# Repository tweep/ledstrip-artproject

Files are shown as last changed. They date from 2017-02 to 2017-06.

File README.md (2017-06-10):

# Ledstrip Art project 
This project aims to make an LED art installation of the Vasily Kadinsky "einige kreise" picture - see pictures below. 
The installation will be driven by 2 Arduino Mega 2560's ( one for the LEDs, one for a remote control ); each colored 
circle can change color independently.  

Here's the final installation - you fine some pictures if you scroll down, or look [here](./pics/)

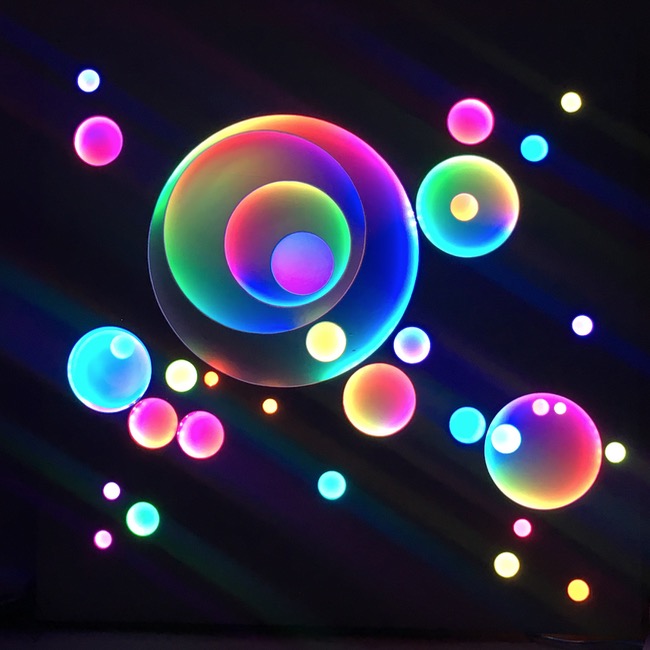
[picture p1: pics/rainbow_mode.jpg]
Final installation
 

## What i could have done better
- every plywood sheet should have had a SINGLE connector to connect to the MAIN sheet with 
  the microcontrollers. Currently I have one centralized place where all connects - so taking the 
  whole piece apart is a big mess as i have to disconnect 36 connectors and loose all the pin-layout. 
  Not good. Next time, one central connector per Plywood sheet, with a single cable running to 
  the microcontroller. Not 1000's of cables. it's also easer to build as you can measure the
  length of the cables better. 
- do the edges in an angled fashion so it looks more like "floating" / cut the sides in angles
  where the top plywood is smaller than the one below, than the one below, than the one below...

## Notes 
Here are some good reads on colors and color theory: 

[The color wheel](https://blog.asmartbear.com/color-wheels.html) 
[Hue angle transitions](http://rileyjshaw.com/blog/hue-angle-transitions/)

I created a nice color transition in [JSfiddle](https://jsfiddle.net/user/vogelj/).

## Stuff needed 
- thin pywood sheets ( 5mm think so it's not too heavy 
  ( home depot, cut the 8x4 sheets into 4 x 4 squares ) 
- 2 x Arduino Mega 2560 
- LED strips WS2812B 5V
- Power supply : I ordered a fan-less Mean Well HSN 300 watts 5V supply. 
  (That's 60 Amps - I went a little over the top as i did not now at the start 
   how many LEDs I have to power. I used 700 LEDS which need  42 Amps max. 
  [Power supply](http://www.trcelectronics.com/View/Mean-Well/HSN-300-5A.shtml)
- JST connectors and 3-cables from Amazon
- Soldering iron 
- Solder - Mandala Crafts 60 40 0.6mm 0.8mm 1mm 1.5mm 2% Flux Rosin Core Solder Wire (50g, 60 40, 0.8mm)
  https://www.amazon.com/dp/B06XX27KZ1/

## Libraries /  Software / Dependencies
I'm using the FastLED library to drive my WS2812B 5V LED strips which have individually addressable LEDs. I bought them online. 
 
- [Arduino FastLED library](https://github.com/FastLED/FastLED)
- Infrared library ( currently used: : IRemote. I like to switch to the IRlib2 later. It has conflicts with the interrupts used by FastLED, 
  so I decided to use 2 Arduinos: one to deal with the remote and the LCD display, and one which drives the LEDs.
- [Easytransfer_I2C](has://github.com/madsci1016/Arduino-EasyTransfer) - to communicate between 2 Arduinos via Serial interface 

## Project status and files 
After realizing that there are some timing problems when using the FastLed library together with an IR-remote (the FastLed library turns all interrrupts off), I decided to use 2 Arduino boards for the project: 

 1.  1 x Arduino MEGA to drive the User interface ( the MASTER) 
 * LCD display with keypad 
 * Menu structure on LCD 
 * IR receiver to remote control the same menu with an IR remote 
 * uses EasyTransfer library to send data via I2C to the Arduino Mega  

 2.  1 x Arduino MEGA which controls the FastLED patterns and strands (the SLAVE)
 * uses FastLED library to drive the strands 
 * EasyTransfer library to receive data via I2C from the Arduino Uno menu / UI and translate them into 
   visible patterns
 * code for patterns, transitions, and FastLED configuration 
 * I'm driving 700 LEDS distributed over 36 strands. Each strand has a differnt number of LEDs; 
   this was a bit of a challenge as the 'usual' way of using a two-dimensional array for all LEDS 
   eats up too much memory. 
   I had to modfify the FastLED library to add some methods which allow me to work with a different 
   data structure.

## Todo 
- switch to differnt IR library ( see [example](./EXAMPLE_irlib2_remote_fastled)
- 
## Code  

## Code Stages 

### UNO_LCD_I2C_TX_example 
File UNO_LCD_I2C_TX_example.ino contains a fully working example for the Arduino Uno which 
  - shows a menu for 2 LED strands + some global configuration 
  - interfaces with an IR remote to use the menu   
  - interfaces with a keypad on the menu to choose functions 
  - sends the data to the Arduno Mega via I2C communication 

This example uses the following libraries: 
 - Wire.h
 - EasyTransferI2C.h
 - LiquidCrystal.h
 - MenuEntry.h"
 - MenuLCD.h"
 - MenuManager.h"
 - IRremote.h
 - IRremoteInt.h

## Todo: 

- allow to control brightness of strands individuall ( could be combined with the on/off possibility )    
- allow to switch individual strands on/off 

- Create solid patterns: red, green, blue
  Create solid transitions of full strand : red -> green -> blue -> ...
- add new transitons ( turning / rgb color circles ) 
- add beserker mode ( blinking in high frequency with different colors ) 

- store favorite configs and add possibility to cycle trough them. [ 0, 2, 1, 0 ] ... strips don't need to be all the same theme

- adjust speed of some patterns ? 

## Done : 
- reset function [ go back to start config ] 
- add possibility to cycle all strands trough all patterns together 
- switch all strands on / off 
- control brightness of all strands with single button  
- change the strand themes individually per strand 

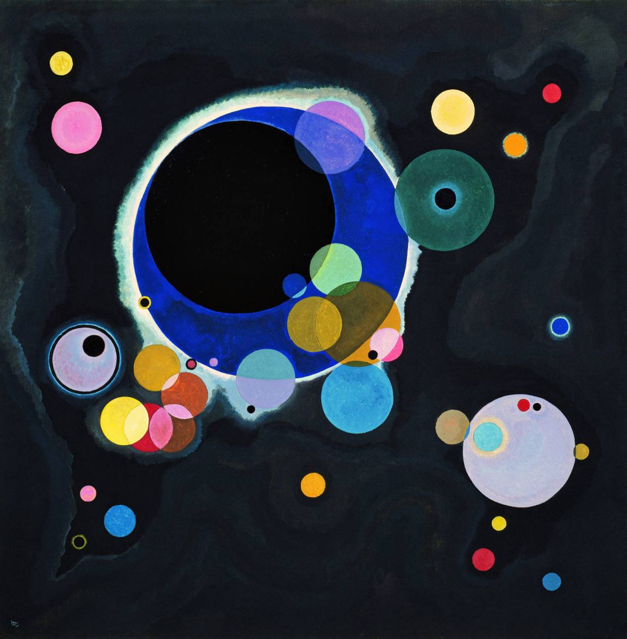
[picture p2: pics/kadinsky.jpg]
Kadinsky picture
 

Final installation 

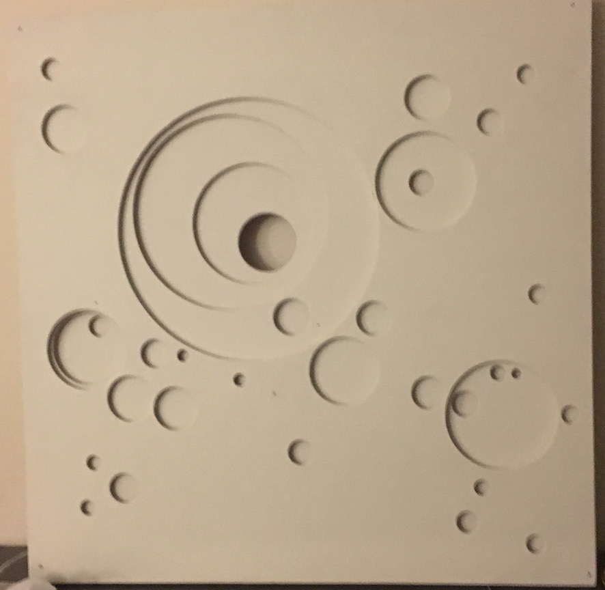
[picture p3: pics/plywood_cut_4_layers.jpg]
Daylight
 

More pictures can be found [here](./pics/.jpg)

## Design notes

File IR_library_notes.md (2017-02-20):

# Notes on IR Libraries 

There are serveral libraries out there which support IR receviers ( and the sending of IR signals). The first library was written by Ken Shirriff. 

## IRremote.h and IRremoteInt.h 
Written by Ken Shiriff. Latest version: 2.2.1 
Available here: https://github.com/shirriff/Arduino-IRremote
Works ok, but seems to not handle interrupts - the IR singal gets only read 
every now-and-than.  
Conflicts: No conflicts with FastLED libary.

## IRlib 
Writteb by Cyborg5. 
Available here : https://github.com/cyborg5/IRLib/
Conflicts: 

## IRlib2  
Written by Cyborg.
Available here: https://github.com/cyborg5/IRLib2
Conflicts: This library has problems when used with the FastLED library - when calling the delay function ( which sets the frame rate ) - the IR remote codes are not read correctly anymore: 

     FastLED.delay(40) 

## Infrared4Arduino
Written by bengtmartensson
Available here : https://github.com/bengtmartensson/Infrared4Arduino/
http://www.harctoolbox.org/Infrared4Arduino.html
Conflicts: ? 
Notes: Unsure if this lib works with interrupts or not.

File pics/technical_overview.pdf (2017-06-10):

# Kandinsky goes LED!

Jan Vogel

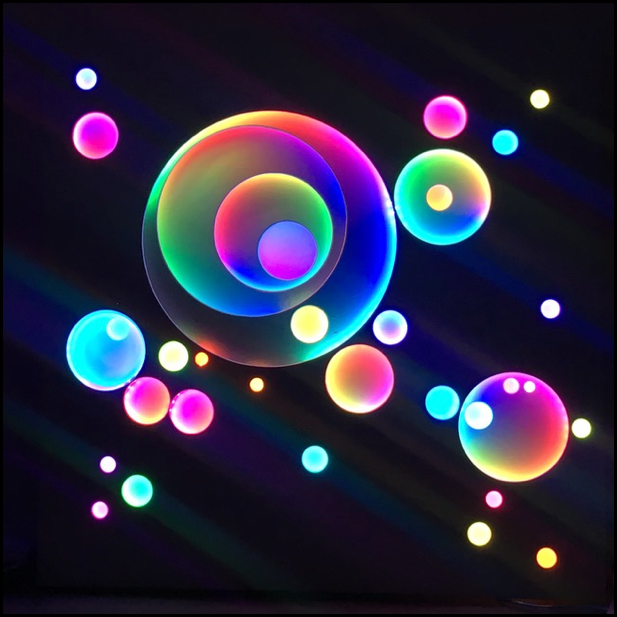
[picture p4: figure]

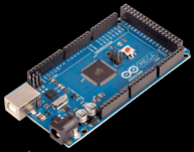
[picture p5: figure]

I2C communication

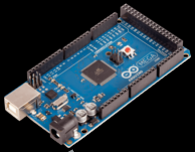
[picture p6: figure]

36 WS2812B
LED strips
(700 LEDs)

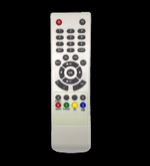
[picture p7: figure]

700 * 60 mA / 1000 = 42 Amp

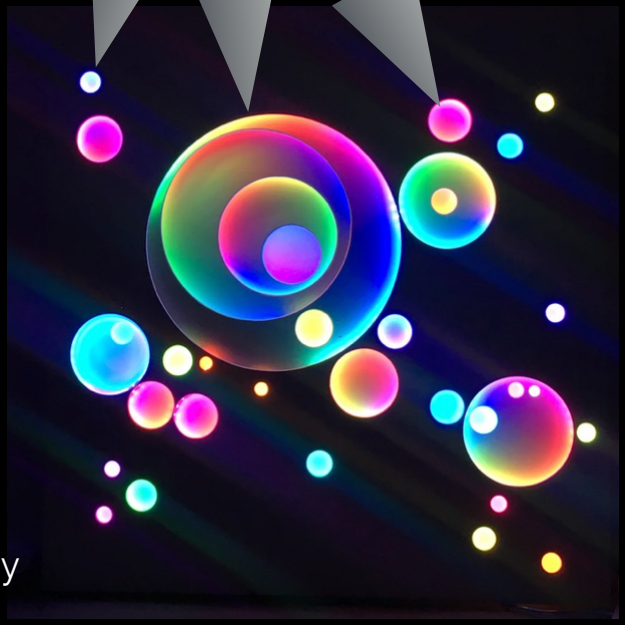
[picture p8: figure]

300 w / 5 V / 60 Amp fan-less power supply Mean Well HSN-300-5A

SEND_DATA_STRUCTURE{
int ledStripToConfigure;
int pattern;
int spd;
int bright;
int color;
} sendLEDConfig;

# To do better

- for global config changes ( like turn stuff off ), only send 1 config, and the SLAVE should then loop trough all strands and set the defaults (so we don’t have to send 36 configswe just send a single GLOBAL config which SLAVE resolves into 36 smaller ones
- more patterns
- easy way to make new patterns
- new IR library to resolve the fuzzy control via IR
- fix the one weird LED strand

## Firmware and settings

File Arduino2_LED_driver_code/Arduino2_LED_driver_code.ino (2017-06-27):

/* ARDUINO LED SLAVE 
   - drives the LEDS strands
   - knows all about the strands ( nr LEDs and PINs)
   - implementes their actions (transitions)
*/   

#include <Wire.h>
#include <EasyTransferI2C.h>
#include <FastLED.h>

FASTLED_USING_NAMESPACE
#define COLOR_ORDER GRB
#define ARRAY_SIZE(A) (sizeof(A) / sizeof((A)[0]))
#define I2C_SLAVE_ADDRESS 9

#define NUM_STRIPS 36

 
CRGB leds[774]; // one-dimensional array, better memory use.

/* methods to try ;
 *  fill_solid( leds, int numToFill,  const struct CRGB& color)  // operates on an array of LEDS rather; needs to operate on an array + an offset instead 
 *  fill_rainbow( leds, numtofill ) - fills a whole strip with rainbow colors
 *  Sigh, all methods opereate on an array of LEDs
 *  
 */

/* Another way to do this is : 36 of these arrays. Maybe can we have one array with pointers to point to these ? 
 *  How can we create an array of pointers ? in a for loop ? 
 *  for ( num strips ) { 
 *    ledRegister[1] = *create_array_with_leds(size) 
 *    }
 * CRGB redLeds[10];
   CRGB greenLeds[60];
   CRGB blueLeds[];
 */


/*       STRAND    S0  S1  S2  S3  S4   5   6   7   8  9   10   11  12 13  14   15  16  17  18  19  20  21   22  23  24  25  26  27  28  29  30  31 32   33 34  35
 *       NR_LEDS   13, 21, 46, 31, 12, 10, 11, 14, 19, 17, 12,  5, 90, 75,  60, 28, 15, 7,  12, 27, 14, 36,  15, 19, 14, 12, 12, 14, 41, 14, 8,  6, 8,    9, 12, 15 
 *          PIN    47  32  49   5  34  31   2   3   8  7   24   23  6  12   4   35  51  22  36  25  11  45   43  44  27  53  50  48  10  13  52  46 9    26 28, 29

*/

                   //        STRAND    S0  S1  S2  S3  S4 -  5   6   7   8   9  -  10  11  12  13  14 -  15  16  17  18  19 - 20  21  22  23  24  - 25  26  27  28  29 - 30  31  32  33  34  35
byte nrLedsPerStrand[NUM_STRIPS]    = {13, 21, 46, 31, 12,  10, 11, 14, 19, 17,    12,  5, 90, 75, 60,   28, 15,  7, 12, 27,  14, 36, 15, 19, 14,   12, 12, 14, 41, 14,   8,  6,  8,  9, 12, 15 };
//byte stripPin[NUM_STRIPS]           = {47, 32, 49,  5, 34,  31,  2,  3,  8,  7,    24, 23,  6, 12,  4,   35, 51,  22,36, 25,  11, 45, 43, 44, 27,   53, 50, 48, 10, 13,  52, 46,  9, 26, 28, 29 };



EasyTransferI2C ET;


// ---- global variables to store data for the PATTERNS
boolean gSwitch               = true; // global variable to remember current ON/OFF status
byte    gstrand               = 0;    // global variable to point to current strand.
byte    gHue[NUM_STRIPS]      = {0, 0, 0, 0, 0, 0, 0, 0, 0, 0, 0, 0, 0, 0, 0, 0, 0, 0, 0, 0, 0, 0, 0, 0, 0, 0, 0, 0, 0, 0, 0, 0, 0, 0, 0,0 };  // rotating "base color" used by many of the patterns, so each strip can have different gHue

// TODO Master: have longer sleep timer in setup()
// sleep timer - to turn LED off after 60 min.

struct RECEIVE_DATA_STRUCTURE {
  //THIS MUST BE EXACTLY THE SAME ON THE OTHER ARDUINO
  int ledStripToConfigure;
  int pattern;
  int spd;
  int bright;
  int color;
} mydata;

typedef struct {    // Structure to hold a copy of the configuration of each strand
  int pattern;
  int spd;
  int bright;
  int color;
} struct_ledconf;
struct_ledconf ledConfig[NUM_STRIPS];

CLEDController *controllers[NUM_STRIPS];


void setup() {
  Serial.begin(115200);

  controllers[0] = &FastLED.addLeds<WS2812B, 47>(leds, getOffsetOfStrand(0), nrLedsPerStrand[0]).setCorrection(TypicalLEDStrip);
  controllers[1] = &FastLED.addLeds<WS2812B, 32>(leds, getOffsetOfStrand(1), nrLedsPerStrand[1]).setCorrection(TypicalLEDStrip);
  controllers[2] = &FastLED.addLeds<WS2812B, 49>(leds, getOffsetOfStrand(2), nrLedsPerStrand[2]).setCorrection(TypicalLEDStrip);
  controllers[3] = &FastLED.addLeds<WS2812B,  5>(leds, getOffsetOfStrand(3), nrLedsPerStrand[3]).setCorrection(TypicalLEDStrip);
  controllers[4] = &FastLED.addLeds<WS2812B, 34>(leds, getOffsetOfStrand(4), nrLedsPerStrand[4]).setCorrection(TypicalLEDStrip);

  controllers[5] = &FastLED.addLeds<WS2812B, 31, GRB>(leds,getOffsetOfStrand(5),nrLedsPerStrand[5]).setCorrection(TypicalLEDStrip);
  controllers[6] = &FastLED.addLeds<WS2812B,  2, GRB>(leds,getOffsetOfStrand(6),nrLedsPerStrand[6]).setCorrection(TypicalLEDStrip);
  controllers[7] = &FastLED.addLeds<WS2812B,  3, GRB>(leds,getOffsetOfStrand(7),nrLedsPerStrand[7]).setCorrection(TypicalLEDStrip);
  controllers[8] = &FastLED.addLeds<WS2812B,  8, GRB>(leds,getOffsetOfStrand(8),nrLedsPerStrand[8]).setCorrection(TypicalLEDStrip);
  controllers[9] = &FastLED.addLeds<WS2812B,  7, GRB>(leds,getOffsetOfStrand(9),nrLedsPerStrand[9]).setCorrection(TypicalLEDStrip);

  controllers[10] = &FastLED.addLeds<WS2812B, 24, GRB>(leds,getOffsetOfStrand(10),nrLedsPerStrand[10]).setCorrection(TypicalLEDStrip);
  controllers[11] = &FastLED.addLeds<WS2812B, 23, GRB>(leds,getOffsetOfStrand(11),nrLedsPerStrand[11]).setCorrection(TypicalLEDStrip);
  controllers[12] = &FastLED.addLeds<WS2812B,  6, GRB>(leds,getOffsetOfStrand(12),nrLedsPerStrand[12]).setCorrection(TypicalLEDStrip);
  controllers[13] = &FastLED.addLeds<WS2812B, 12, GRB>(leds,getOffsetOfStrand(13),nrLedsPerStrand[13]).setCorrection(TypicalLEDStrip);
  controllers[14] = &FastLED.addLeds<WS2812B,  4, GRB>(leds,getOffsetOfStrand(14),nrLedsPerStrand[14]).setCorrection(TypicalLEDStrip);

  controllers[15] = &FastLED.addLeds<WS2812B, 35, GRB>(leds,getOffsetOfStrand(15),nrLedsPerStrand[15]).setCorrection(TypicalLEDStrip);
  controllers[16] = &FastLED.addLeds<WS2812B, 51, GRB>(leds,getOffsetOfStrand(16),nrLedsPerStrand[16]).setCorrection(TypicalLEDStrip);
  controllers[17] = &FastLED.addLeds<WS2812B, 22, GRB>(leds,getOffsetOfStrand(17),nrLedsPerStrand[17]).setCorrection(TypicalLEDStrip);
  controllers[18] = &FastLED.addLeds<WS2812B, 36, GRB>(leds,getOffsetOfStrand(18),nrLedsPerStrand[18]).setCorrection(TypicalLEDStrip);
  controllers[19] = &FastLED.addLeds<WS2812B, 25, GRB>(leds,getOffsetOfStrand(19),nrLedsPerStrand[19]).setCorrection(TypicalLEDStrip);


  controllers[20] = &FastLED.addLeds<WS2812B, 11, GRB>(leds,getOffsetOfStrand(20),nrLedsPerStrand[20]).setCorrection(TypicalLEDStrip);
  controllers[21] = &FastLED.addLeds<WS2812B, 45, GRB>(leds,getOffsetOfStrand(21),nrLedsPerStrand[21]).setCorrection(TypicalLEDStrip);
  controllers[22] = &FastLED.addLeds<WS2812B, 43, GRB>(leds,getOffsetOfStrand(22),nrLedsPerStrand[22]).setCorrection(TypicalLEDStrip);
  controllers[23] = &FastLED.addLeds<WS2812B, 44, GRB>(leds,getOffsetOfStrand(23),nrLedsPerStrand[23]).setCorrection(TypicalLEDStrip);
  controllers[24] = &FastLED.addLeds<WS2812B, 27, GRB>(leds,getOffsetOfStrand(24),nrLedsPerStrand[24]).setCorrection(TypicalLEDStrip);

  
  controllers[25] = &FastLED.addLeds<WS2812B, 53, GRB>(leds,getOffsetOfStrand(25),nrLedsPerStrand[25]).setCorrection(TypicalLEDStrip);
  controllers[26] = &FastLED.addLeds<WS2812B, 50, GRB>(leds,getOffsetOfStrand(26),nrLedsPerStrand[26]).setCorrection(TypicalLEDStrip);
  controllers[27] = &FastLED.addLeds<WS2812B, 48, GRB>(leds,getOffsetOfStrand(27),nrLedsPerStrand[27]).setCorrection(TypicalLEDStrip);
  controllers[28] = &FastLED.addLeds<WS2812B, 10, GRB>(leds,getOffsetOfStrand(28),nrLedsPerStrand[28]).setCorrection(TypicalLEDStrip);
  controllers[29] = &FastLED.addLeds<WS2812B, 13, GRB>(leds,getOffsetOfStrand(29),nrLedsPerStrand[29]).setCorrection(TypicalLEDStrip);
  
  controllers[30] = &FastLED.addLeds<WS2812B, 52, GRB>(leds,getOffsetOfStrand(30),nrLedsPerStrand[30]).setCorrection(TypicalLEDStrip);
  controllers[31] = &FastLED.addLeds<WS2812B, 46, GRB>(leds,getOffsetOfStrand(31),nrLedsPerStrand[31]).setCorrection(TypicalLEDStrip);
  controllers[32] = &FastLED.addLeds<WS2812B,  9, GRB>(leds,getOffsetOfStrand(32),nrLedsPerStrand[32]).setCorrection(TypicalLEDStrip);
  controllers[33] = &FastLED.addLeds<WS2812B, 26, GRB>(leds,getOffsetOfStrand(33),nrLedsPerStrand[33]).setCorrection(TypicalLEDStrip);
  controllers[34] = &FastLED.addLeds<WS2812B, 28, GRB>(leds,getOffsetOfStrand(34),nrLedsPerStrand[34]).setCorrection(TypicalLEDStrip);

  controllers[35] = &FastLED.addLeds<WS2812B, 29, GRB>(leds,getOffsetOfStrand(35),nrLedsPerStrand[35]).setCorrection(TypicalLEDStrip);


  for ( int j = 0; j < NUM_STRIPS; j++ ) {
    Serial.print("Strip"); 
    Serial.println(j); 
    FastLED[j].showLeds(128); // set initial brightness of strip
    FastLED.show();
    gstrand=j;
    colorStripBlack();
    delay(50);

    // set very initial config 
      ledConfig[j].pattern      = 6; 
      ledConfig[j].spd          = 0;
      ledConfig[j].bright       = 0;
      ledConfig[j].color        = 0;

    
  }

  // -------- EasyTransfer --------

  Wire.begin(I2C_SLAVE_ADDRESS);
  //start the library, pass in the data details and the name of the serial port. Can be Serial, Serial1, Serial2, etc.
  ET.begin(details(mydata), &Wire);
  Wire.onReceive(receive);   //define handler function on receiving data
  Serial.println("Ready to receive data");
}


typedef void (*SimplePatternList[])();
// array with list of patters which serve as functions. problem is we can't hand arguments over so we use global variables
SimplePatternList gPatterns = { //breathing_led_heartbeat, 
                               rainbow, 
                                rainbowWithGlitter, 
                                confetti, 
                                sinelon, 
                                juggle,
                                bpm, 
                                fadeToBlack,
                                colorStripRed };

int gNrPatterns = ARRAY_SIZE(gPatterns);


int getOffsetOfStrand (int strand) {
  int offset = 0;
  for (int i = 0; i < strand; i++) { 
    offset+= nrLedsPerStrand[i];   
  }
  return offset; 
}



void loop() {
  // BEGINNING OF -loop-
  
  if (ET.receiveData()) {
      int strip = mydata.ledStripToConfigure;

      // if we retrieve GLOBAL data we apply it to all strands 
      if (strip == -1) { 
           for (byte i = 0; i < NUM_STRIPS ; i++ ) {
             ledConfig[i].pattern      = ( mydata.pattern % gNrPatterns);
             ledConfig[i].spd          = mydata.spd;
             ledConfig[i].bright       = mydata.bright;
             ledConfig[i].color        = mydata.color;
             controllers[i]->showLeds(ledConfig[i].bright);
           }
      }else { 
        ledConfig[strip].pattern      = ( mydata.pattern % gNrPatterns);

        ledConfig[strip].spd          = mydata.spd;
        ledConfig[strip].bright       = mydata.bright;
        ledConfig[strip].color        = mydata.color;
        controllers[strip]->showLeds(ledConfig[strip].bright);
      
       Serial.println("Retrieving data...");
       Serial.print(" Strip: "); Serial.print(mydata.ledStripToConfigure);
       Serial.print(" pattern: "); Serial.print(mydata.pattern);
       Serial.print(" speed: "); Serial.print(mydata.spd);
       Serial.print(" brigh: "); Serial.print(mydata.bright);
       Serial.print(" color: "); Serial.print(mydata.color);
       Serial.println(" ");
      }
  }

  // Loop trough all strands and write/apply the values of the ledConfig to each strand.
  for (byte i = 0; i < NUM_STRIPS ; i++ ) {
    gstrand = i; // global index to point to current strand. gstrand (global Var!!) is used in the subroutines which do patterns. 
    // DONT change this !
    // the challenge is that we can't had this parameter over to the routine itself.
    gPatterns[ledConfig[i].pattern]();
    controllers[i]->showLeds(ledConfig[i].bright);
  }
 //  delay(3);
   // END OF -loop-
}

void receive(int numBytes) {
}

void breathing_led_heartbeat() {
  int offset = getOffsetOfStrand(gstrand);

  /* uploaded 26-06-2017
    todo:
      - only light up a certain nu ber of circles at the same time ( like 2,3,4 ) 
      - randomly switch to a new circle once the currenlty light cirlce is off
      - ( need a factor for each strand to define the speed of light on / light off 
      - not all cirlces adaapot the new (led breathing pattern - why ? ) some stay on the previous pattern.
      - refactor how global pattersn are sent. 
  */

  float val = (exp(sin(millis()/(gstrand*200.0)*PI)) - 0.36787944)*108.0;
  Serial.print("gstrand: ");
  Serial.print(gstrand);
  Serial.print("  val : ");
  Serial.print(val);
  Serial.print(" ghue :");
  Serial.println(gHue[gstrand]);

  // this can be done faster using the method in fill_rainbow() or fill_solid 
 // for (byte x=0; x< nrLedsPerStrand[gstrand]; x++){
  //   leds[offset+x] = CHSV( gHue[gstrand] , 128, 255); // random number from 0-255
// }
  ledConfig[gstrand].bright=val;

 fill_solid(&leds[offset], nrLedsPerStrand[gstrand],  CHSV( gHue[gstrand] , 255, 255));

 // only change the color once we 'breathed out'  
  if(val < 0.1 ){
    gHue[gstrand] = gHue[gstrand]+random8(0,25);
    //gHue[gstrand] = gHue[gstrand]+5;
     // gHue[gstrand] = random8();

  }
}




void rainbow() {
  // use global variable strand
  gHue[gstrand]++;

 //fill_rainbow( struct CRGB * pFirstLED, int numToFill, uint8_t initialhue, uint8_t deltahue = 5);

 //  fill_rainbow(leds , nrLedsPerStrand[gstrand], gHue[gstrand], 7);

  fill_rainbow(&leds[getOffsetOfStrand(gstrand)] , nrLedsPerStrand[gstrand], gHue[gstrand], 3);

 // fill_rainbow(leds, getOffsetOfStrand(gstrand) , nrLedsPerStrand[gstrand], gHue[gstrand], 7);

}

void rainbowWithGlitter() {
  rainbow();
  addGlitter(80);
}

// change individual pixel a strand
void addGlitter( fract8 chanceOfGlitter) {
  // create random number between 0-255. this number is smaller than ChanceOfGlitter,
  // then create a random number from 0 to

  if ( random8() < chanceOfGlitter) {

   int glitterPixel = random16(nrLedsPerStrand[gstrand]) + getOffsetOfStrand(gstrand);
   leds[glitterPixel] += CRGB::White;
  }
}

void fadeToBlack() {
  int offset = getOffsetOfStrand(gstrand);
  
  for (byte i = 0; i < nrLedsPerStrand[gstrand]; i++ ) {
    leds[offset+i].fadeToBlackBy( 64 );
  }
}

void confetti() {
  // random colored speckles that blink in and fade smoothly
  int offset = getOffsetOfStrand(gstrand);
//  fadeToBlackBy( leds,offset, nrLedsPerStrand[gstrand], 10);
  fadeToBlackBy( &leds[offset], nrLedsPerStrand[gstrand], 20);  

  int pos = random16(nrLedsPerStrand[gstrand]);
  leds[offset+pos] += CHSV( gHue[gstrand] + random8(64), 200, 255);
}

// change individual pixel a strand
void sinelon() {
  // a colored dot sweeping back and forth, with fading trails
  int offset = getOffsetOfStrand(gstrand);
    fadeToBlackBy( &leds[offset], nrLedsPerStrand[gstrand], 20);  

  //fadeToBlackBy( leds,offset, nrLedsPerStrand[gstrand], 20);
  int pos = beatsin16(13, 0, nrLedsPerStrand[gstrand]);
  leds[offset+pos] += CHSV( gHue[gstrand], 255, 192);
}


void bpm() {
  // colored stripes pulsing at a defined Beats-Per-Minute (BPM)
  uint8_t BeatsPerMinute = 62;
  CRGBPalette16 palette = PartyColors_p;
  int offset = getOffsetOfStrand(gstrand);

  uint8_t beat = beatsin8( BeatsPerMinute, 64, 255);
  for (byte i = 0; i < nrLedsPerStrand[gstrand]; i++) { //9948
    leds[offset+i] = ColorFromPalette(palette, gHue[gstrand] + (i * 2), beat - gHue[gstrand] + (i * 10));
  }
}


void juggle() {
  // eight colored dots, weaving in and out of sync with each other
  int offset = getOffsetOfStrand(gstrand);
  fadeToBlackBy( &leds[offset], nrLedsPerStrand[gstrand], 20);  

 // fadeToBlackBy( leds,offset, nrLedsPerStrand[gstrand], 20);
 
  byte dothue = 0;
  for ( int i = 0; i < 8; i++) {
   leds[offset + beatsin16(i + 7, 0, nrLedsPerStrand[gstrand])] |= CHSV(dothue, 200, 255);
    dothue += 32;
  }
}


void colorStripRed() {
  int offset = getOffsetOfStrand(gstrand);
  fill_solid(&leds[offset], nrLedsPerStrand[gstrand], CRGB::Red);
}
    
void colorStripBlack() {
  int offset = getOffsetOfStrand(gstrand);
    fill_solid(&leds[offset], nrLedsPerStrand[gstrand], CRGB::Black);
}

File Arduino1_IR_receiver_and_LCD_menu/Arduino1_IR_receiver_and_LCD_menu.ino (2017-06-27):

/*  ARDUINO UNO - SENDING / LCD
 *  - Infrared IR remote receiver on port 2 
 *  - SDA / SCL on freigesaegte ports 
 *  no GROUND connection
 *  - LCD on various other ports 
 *  
 *  This sketch is running on an Arduino MEGA. It takes input from an LCD keypad or an infrared remote. 
 *  It sends the desired configuration to the connected other Arduino. 
 *  Problem: At the moment, we use a "global" parameter to send global configs, like brightness or turn on/off. 
 *  the logic is than translated at the FASTLED Slave side. 
 *  we could also implement the logic in here (LCD MENU) and then just send it over ? 
 *  IF LCD doees logic: 
 *  - know what pattern "go black" is 
 *  - set information for all connected strands over. transmit time + reaction time 
 *    vs. send one information over, then code takes it from there...
 */

 
#include <Wire.h>
#include <EasyTransferI2C.h>
#include <LiquidCrystal.h>
#include "MenuEntry.h"
#include "MenuLCD.h"
#include "MenuManager.h"

#include <IRLibDecodeBase.h> 
#include <IRLib_P07_NECx.h>  // must be first but others can be any order.
#include <IRLibCombo.h>      // After all protocols, include this
IRdecode myDecoder;          // instance of IRdecoder

//#include <IRLibRecv.h>      // Include a receiver either this or IRLibRecvPCI or IRLibRecvLoop
//IRrecv myReceiver(53);  //pin number for the receiver

#include <IRLibRecvLoop.h>  // this receiver can be delayed which works better for my remote so cmds are not send twice
        
IRrecvLoop myReceiver(53);  //pin number for the receiver



/* 
 * This example shows how to connect an 16x2 display similar to this one: 
 * https://www.amazon.com/gp/product/B006OVYI1G/
 * 
 * Note: The pins are slightly different then the ones in the original example.
 * 
 */ 
 
const int LCDD7 = 7;
const int LCDD6 = 6;
const int LCDD5 = 5;
const int LCDD4 = 4;
const int LCDE  = 9;
const int LCDRS = 8;


#define NUM_STRIPS 36
#define gNrPatterns  7   // 0 to 7 - change this if you add new patterns. not ideal really. just do ++ and use type byte and check on slave if it's out of aray 
#define blackPattern 0

bool configUpdated = false;
bool gSwitch       = false;
bool gConf         = false;
byte gPattern      = 0;
int  gBright       = 128;     // start brightness

// these values will be applied to ALL strands at startup
byte initialPattern    = 1;
byte initialSpeed      = 60;
byte initialBrightness = 200;

byte gPrevPattern[NUM_STRIPS];

EasyTransferI2C ET; 

struct SEND_DATA_STRUCTURE{
  //THIS MUST BE EXACTLY THE SAME ON THE OTHER ARDUINO
  int ledStripToConfigure;
  int pattern;
  int spd;
  int bright;
  int color;
} mydata; 

typedef struct{
  int pattern;
  int spd;
  int bright;
  int color;
} struct_ledconf;
struct_ledconf ledConfig[NUM_STRIPS];


#define I2C_SLAVE_ADDRESS 9  

//Now create the MenuLCD and MenuManager classes.
MenuLCD g_menuLCD( LCDRS, LCDE, LCDD4, LCDD5, LCDD6, LCDD7, 16, 2);

const bool doRootAction = true;
MenuManager g_menuManager( &g_menuLCD, doRootAction);  //pass  g_menuLCD object to g_menuManager with the & operator (pass the address)
                                                      // also pass boolean variable to configure the Menu if callback functions for 
                                                      // menu items with children are executed or not

unsigned int g_isDisplaying = false;


/*
 *    1. LED strip
 *    |     |----Choose Pattern
 *    |     |----Set Speed 
 *    |     |----Set Color
 *    |     |----Set Brightness
 *    |     |----Turn Strand ON
 *    |     |----Turn Strand OFF
 *    |              
 *    2. LED strip
 *    |     |----Choose Pattern
 *    |     |----Set Speed 
 *    |     |----Set Color
 *    |     |----Set Brightness
 *    |     |----Turn Strand ON
 *    |     |----Turn Strand OFF
 *    |              
 *    Global configuration 
 *    |     |---Set global brightness
 *    |     |---Set global color
 *    |
 *    |- Switch On/Off
 */


/* LED MENU configuration for different strips */ 

void configureLEDstripOne ( char * pMenuText, void * pUserData ) {
  // set the variable at address pUserData to value 0 (address gets handed over in menu with &variable)
  // dereference data type which is userData
   *(( int *) pUserData) = 0;
}
void configureLEDstripTwo ( char * pMenuText, void * pUserData ) {
   // dereference data type which is userData
   *(( int *) pUserData) = 1;
}
void configureLEDstripThree ( char * pMenuText, void * pUserData ) {
   *(( int *) pUserData) = 2;
}
void configureLEDstripFour ( char * pMenuText, void * pUserData ) {
   *(( int *) pUserData) = 3;
}
void configureLEDstripAll ( char * pMenuText, void * pUserData ) {
   // dereference data type which is userData
   *(( int *) pUserData) = 99;
}

/*This callback uses the built-in Int Input routine in MenuManager.h to request input of a integer number from the 
  user.  Control will pass to the DoIntInput function until the user finishes.  the g_timerTime will be set to the 
  value the user selects.
*/


void SetPattern( char* pMenuText, void *pUserData ) {
  const char *pLabel = (char *)"Choose Pattern";

  int iNumLabelLines = 1;
  int iMin   = 1;
  int iMax   = 10;
  // previously stored value 
  int iStart = ledConfig[mydata.ledStripToConfigure].pattern;  // global       
  int iStep  = 1;  //Each user input action (such as a push of button) will step this amount
   g_menuManager.DoIntInput( iMin, iMax, iStart, iStep, &pLabel, iNumLabelLines, &ledConfig[mydata.ledStripToConfigure].pattern );    
}
void SetSpeed ( char* pMenuText, void *pUserData ) {
  char *pLabel = (char *)"Choose Speed ^";
  int iNumLabelLines = 1;
  int iMin   = 1;
  int iMax   = 255;
  int iStart = ledConfig[mydata.ledStripToConfigure].spd; 
  int iStep  = 5;
  
  g_menuManager.DoIntInput( iMin, iMax, iStart, iStep, &pLabel, iNumLabelLines,&ledConfig[mydata.ledStripToConfigure].spd );
}
void SetBrightness ( char* pMenuText, void *pUserData ) {
  char *pLabel = (char *)"Choose Brightness";
  int iNumLabelLines = 1;
  int iMin = 1;
  int iMax = 255;
  int iStart = ledConfig[mydata.ledStripToConfigure].bright;
  int iStep = 5;
  g_menuManager.DoIntInput( iMin, iMax, iStart, iStep, &pLabel, iNumLabelLines, &ledConfig[mydata.ledStripToConfigure].bright);

}
void SetColor ( char* pMenuText, void *pUserData ) {
  char *pLabel = (char *)"Choose Color ^:";
  int iNumLabelLines = 1;
  int iMin = 1;
  int iMax = 255;
  int iStart = ledConfig[mydata.ledStripToConfigure].color;

  //Each user input action (such as a push of button) will step this amount
  int iStep = 5;

  g_menuManager.DoIntInput( iMin, iMax, iStart, iStep, &pLabel, iNumLabelLines, &ledConfig[mydata.ledStripToConfigure].color);
}
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

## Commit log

2017-02-16 New files for the LEDStrip artproject NOTE: these files require external libraries. I forked some of those libs.
2017-02-27 Numerous changes and addtl. notes
    [ledstrip_artproject.fzz]
2017-02-28 - latest changes. moved away from global config etc. - all logic to control LEDS is now in LCD menu ( like set black pattern etc)
2017-02-28 - all patterns / setting global brightness etc is now done in LCDmenu. LCDmenu also keeps the original config, and just transmits changes to the LEDslave.
2017-06-07 - addling file with PIN numbers for kadinsky pic
2017-06-25 - added LED breathing effect (similar to apple LED ) to scenes
2017-06-27 - IR receiver code currentlys sends global config changes for every single strand
2017-06-27 -added breathing LED algorithm, but it does not work. ( so this is working code, just the breathing is not so it's not added to a list of common patterns)
    [Arduino2_LED_driver_code.ino]
2017-06-27 - various changes - new IR LIB - removed the storage of the previous pattern before the LEDs get turned off - new default patterns
